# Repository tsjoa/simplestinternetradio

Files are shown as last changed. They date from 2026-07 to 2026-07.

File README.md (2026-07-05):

# Simplest Ever Internet Radio 📻

The simplest, cheapest, and easiest way to connect your classic stereo receiver to the internet and stream high-quality audio! Powered by an **ESP32-S3 Super Mini**, a **PCM5102A (TS1943W) DAC**, and **ESPHome**, this project integrates seamlessly into **Home Assistant** as a standard media player.

With only 6 wires, a mini breadboard, and basic soldering (just header pins and 4 configuration pads), you can build a premium network audio streamer in under 30 minutes.

---

## 🛠️ Hardware Requirements

*   **[ESP32-S3 Development Board](https://www.aliexpress.com/item/1005006637349060.html)** (with PSRAM enabled—see list below)
*   **[PCM5102A (TS1943W) DAC Breakout Board](https://www.aliexpress.com/item/1005010329558215.html)**
*   **Mini Breadboard**
*   **6 Jumper Wires**
*   **USB-C Power Cable & Power Brick**
*   **3.5mm to RCA** (or 3.5mm to 3.5mm) audio cable (to connect the DAC to your stereo's `AUX` or `Line In` port)

### 💡 Verified ESP32-S3 Boards (PSRAM Required)

Since this project buffers audio to prevent stuttering, a board with active PSRAM is mandatory. The following boards have been verified to work:

#### 1. ESP32-S3 Super Mini (PSRAM Edition)
*   **Memory:** 4MB Flash + **2MB PSRAM** (ESP32-S3R2 chip)
*   **PSRAM Type:** Embedded Quad SPI (QSPI)
*   **Pros:** Ultra-compact form factor; fits anywhere.
*   **What to look out for:** Ensure the listing explicitly mentions "PSRAM" or "R2", as there is a cheaper, flash-only version of this exact board that will crash with `ESP_ERR_NO_MEM`.

#### 2. Official Espressif ESP32-S3-DevKitC-1-N8R8 or -N16R8
*   **Memory:** 8MB or 16MB Flash + **8MB PSRAM** (ESP32-S3-WROOM-1 module)
*   **PSRAM Type:** External Octal SPI (OPI)
*   **Pros:** Standard flagship development board, uses the fastest Octal PSRAM, maximum stability in ESPHome.
*   **What to look out for:** Make sure the part number contains the **R8** suffix (e.g., `N8R8`). Avoid the `N8` or `N16` models, which have zero PSRAM.

#### 3. Waveshare ESP32-S3-Zero
*   **Memory:** 4MB Flash + **2MB PSRAM** (ESP32-S3R2 chip)
*   **PSRAM Type:** Embedded Quad SPI (QSPI)
*   **Pros:** Extremely tiny, castellated holes for direct soldering, uses a single USB-C port with an onboard CH343 serial bridge chip for hassle-free flashing.
*   **What to look out for:** Like the Super Mini, double-check that the vendor specifies the PSRAM variant.

#### 4. Seeed Studio XIAO ESP32S3
*   **Memory:** 8MB Flash + **8MB PSRAM**
*   **PSRAM Type:** External Octal SPI (OPI)
*   **Pros:** High-quality, tiny thumbnail form factor, equipped with 8MB of fast Octal PSRAM. Very popular for compact audio and camera projects.
*   **What to look out for:** Do not accidentally buy the standard *XIAO ESP32C3* or *XIAO ESP32S3 Sense* (unless you specifically want the detachable camera addon card that comes with the Sense kit).

#### 🛒 Quick Buying Checklist Rule of Thumb:
When clicking "Add to Cart" on marketplaces like AliExpress or Amazon, look for the variant dropdown menus. **Always select the option labeled `OPI` or `With PSRAM`.** If an option is labeled `qSPI / No PSRAM` or just lists a single number like `16MB`, skip it.

---

## 📐 Wiring Diagrams & Setup

You can find both the Fritzing schematic diagrams and actual reference photographs of the breadboard assembly below. 

The original Fritzing project file is available here: [Simplest Internet Radio HomeAssistant.fzz](Simplest%20Internet%20Radio%20HomeAssistant.fzz)

### 1. Complete Schematic & Build (All Parts)
Here is the Fritzing diagram and the corresponding completed hardware assembly. The boards sit directly over the flat jumper wire routing:

| Fritzing Schematic (All Parts) | Physical Completed Build |
| :---: | :---: |
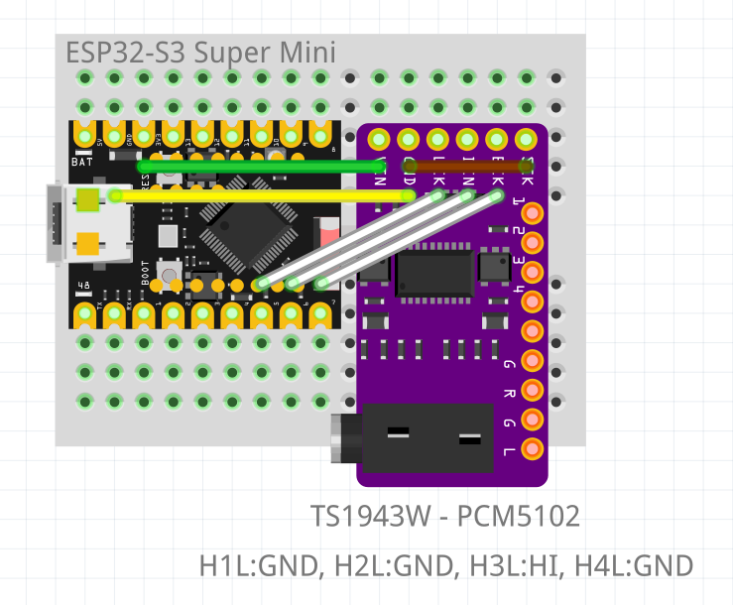
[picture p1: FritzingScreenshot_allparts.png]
All Parts Breadboard Diagram
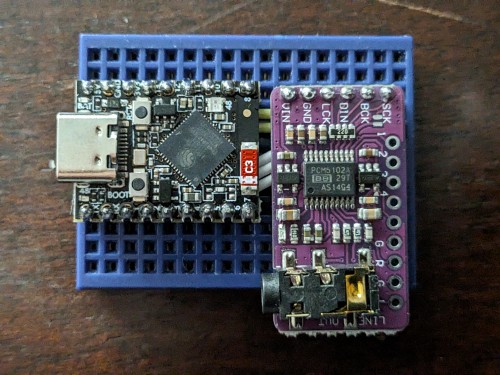
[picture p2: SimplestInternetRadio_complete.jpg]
Physical Completed Build
|  |  |

### 2. Wire Connections Only (Underneath the Boards)
Since the modules cover the jumper wires, here is the diagram and reference photo showing the flat wire routing on the mini breadboard before plugging in the boards:

| Fritzing Wire Connections | Physical Wire Routing |
| :---: | :---: |
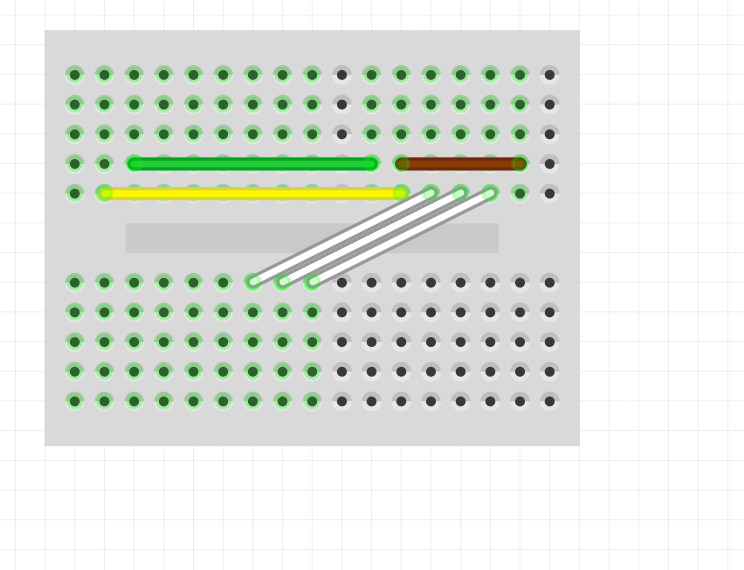
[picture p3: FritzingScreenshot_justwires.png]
Wire Connections Only
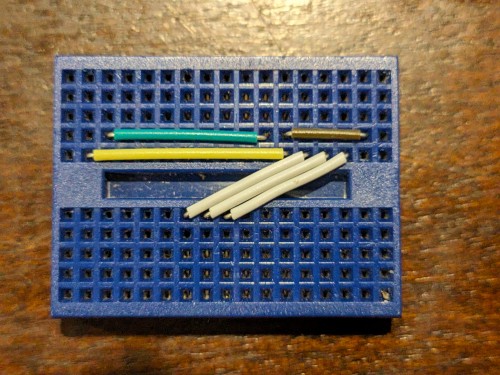
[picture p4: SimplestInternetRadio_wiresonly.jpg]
Physical Wire Routing
|  |  |

---

## 🔌 Step-by-Step Assembly Guide

### Step 1: Hard-Solder the Configuration Bridges

On the back of the PCM5102A breakout board, there are four sets of three-pad jumpers labeled H1L through H4L. Use a soldering iron and a small dab of solder to bridge the **Center** pad to either the **L** (Low) or **H** (High) pad as follows:

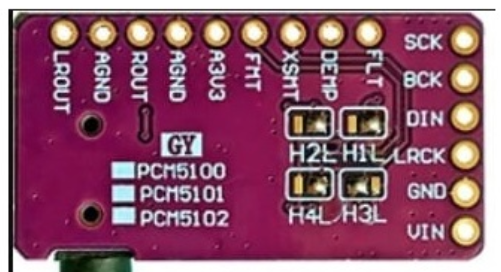
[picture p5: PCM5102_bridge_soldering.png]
PCM5102 Bridge Soldering Diagram


| Jumper | Label | Connection | Setting Details |
| :--- | :--- | :--- | :--- |
| **H1L** | FLT | **Center** ➔ **L** | Normal Latency filter |
| **H2L** | DEMP | **Center** ➔ **L** | De-emphasis Off |
| **H3L** | XSMT | **Center** ➔ **H** | **Unmuted** (Crucial—otherwise no sound!) |
| **H4L** | FMT | **Center** ➔ **L** | I2S Format |

---

### Step 2: Wire the Hardware

Pop your development board and the PCM5102A onto your mini breadboard, and connect them using your jumper wires. 

Here are the pin connections for both the **ESP32-S3 Super Mini** and the **ESP32-C3 Super Mini**:

| PCM5102A DAC Pin | ESP32-S3 Super Mini | ESP32-C3 Super Mini | Function / Description |
| :--- | :--- | :--- | :--- |
| **VCC** (3.3V) | **3V3** | **3V3** (Right side Pin 1) | Main power supply (3.3V) |
| **GND** | **GND** | **GND** (Left side Pin 2 or Right side Pin 2) | System ground |
| **SCK** ➔ **GND** | *N/A* (Ground loop) | *N/A* (Ground loop) | Forces the DAC to generate its own internal clock |
| **LCK** (LRCK) | **GPIO5** | **GPIO10** (Left side Pin 3) | Left/Right Clock (I2S) |
| **DIN** | **GPIO6** | **GPIO20** (Right side Pin 5) | Data In (I2S) |
| **BCK** | **GPIO7** | **GPIO21** (Right side Pin 4) | Bit Clock (I2S) |

> [!IMPORTANT]
> Since the ESP32-C3 Super Mini uses **GPIO 20** and **GPIO 21** for I2S, which are the default hardware serial UART pins, the configuration redirects the `logger` output to the native USB port (`USB_SERIAL_JTAG`). This avoids any digital noise or interference (loud screeching or stuttering) from debug logs.

*Finally, connect the DAC's 3.5mm audio jack to your stereo's `AUX` or `Line In` port using your audio cable.*

---

## 💻 Software Deployment

### 1. Copy the ESPHome Configuration
Select the appropriate configuration file for your micro-controller:
*   **For ESP32-S3 (Recommended):** Use [Simplest Internet Radio HomeAssistant.yaml](Simplest%20Internet%20Radio%20HomeAssistant.yaml).
*   **For ESP32-C3:** Use [Simplest Internet Radio ESP32-C3.yaml](Simplest%20Internet%20Radio%20ESP32-C3.yaml).

Ensure your Wi-Fi details, API keys, and OTA passwords are configured in your ESPHome `secrets.yaml` file.

### 2. Clean Build (Mandatory for ESP32-S3)
Before compiling, you must perform a clean build to apply low-level changes (like PSRAM/SPIRAM enablement for the S3):
1. Open your ESPHome Dashboard.
2. Click the three dots on the device card (`esp32-stereo-link` or `esp32-c3-stereo-link`).
3. Select **Clean Build**.

### 3. Compile and Download
Compile the configuration and download the **factory binary file** to your local computer (e.g., `esp32-stereo-link-firmware.factory.bin` or `esp32-c3-stereo-link-firmware.factory.bin`).

### 4. Flash the Board
Connect your board to your computer via USB and run the command matching your chip:

#### For ESP32-S3:
```bash
sudo esptool --chip esp32s3 --no-stub --port /dev/ttyACM0 write_flash -z 0x0 ~/Downloads/esp32-stereo-link-firmware.factory.bin
```

#### For ESP32-C3:
```bash
sudo esptool --chip esp32c3 --no-stub --port /dev/ttyACM0 write_flash -z 0x0 ~/Downloads/esp32-c3-stereo-link-firmware.factory.bin
```
*(Adjust `/dev/ttyACM0` and the file path according to your OS and download location).*

---

## 🎵 Streaming Audio via Home Assistant

### 1. Discovery
Once the board flashes, boots up, and connects to your Wi-Fi network, Home Assistant will automatically discover it. A new `media_player.stereo_internet_radio` entity will appear under the ESPHome integration.

### 2. Initialize Volume
> [!IMPORTANT]
> If the device connects but stays silent during playback, open the ESP32's local IP address in a web browser. Slide the volume up from **0%** to **80%** to initialize the internal volume state.

### 3. Stream a Station
You can play streams by calling the `media_player.play_media` service. For example, to play Radio Paradise:

```yaml
service: media_player.play_media
target:
  entity_id: media_player.stereo_internet_radio
data:
  media_content_id: "http://stream.radioparadise.com/mp3-192"
  media_content_type: "music"
```

Enjoy your high-fidelity, ultra-simple internet radio! 📻🎶

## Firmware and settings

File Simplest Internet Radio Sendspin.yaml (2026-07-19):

substitutions:
  name: sendspin-stereo-radio
  friendly_name: "Sendspin Stereo Radio"
  startup_sound_file: Home_Connected
  media_sample_rate: 48000

esphome:
  name: ${name}
  friendly_name: ${friendly_name}
  min_version: 2026.6.0
  name_add_mac_suffix: true
  project:
    name: realdeco.sendspin_zero
    version: "2026.6.0"
  on_boot:
    priority: -100
    then:
      - script.execute: led_red

esp32:
  variant: esp32s3
  framework:
    type: esp-idf

logger:
  level: warn

api:
  encryption:
    key: !secret api_encryption_key
  on_client_connected:
    - lambda: |-
        if (!id(boot_sound_played)) {
          id(boot_sound_played) = true;
          if (id(startup_sound_switch).state) {
            id(play_sound)->execute(true, std::string("ready_sound"));
          }
        }

ota:
  - platform: esphome
    id: ota_esphome
    password: !secret ota_password

wifi:
  ssid: !secret wifi_ssid
  password: !secret wifi_password
  output_power: 8.5dB
  ap:
    ssid: ${friendly_name}
    password: !secret ap_password
    ap_timeout: 15s

improv_serial:

captive_portal:

psram:
  mode: quad
  speed: 80MHz
  ignore_not_found: false

# -------------------------------------------------------------------
# DIGITAL AUDIO (I2S) PIPELINE CONFIGURATION
# Matches pinout from Simplest Internet Radio HomeAssistant.yaml:
#   LRCLK (LCK) -> GPIO5
#   BCLK        -> GPIO7
#   DOUT (DIN)  -> GPIO6
# -------------------------------------------------------------------
sendspin:
  id: sendspin_hub

i2s_audio:
  - id: i2s_audio_bus
    i2s_lrclk_pin: GPIO5
    i2s_bclk_pin: GPIO7

speaker:
  - platform: i2s_audio
    id: box_speaker
    i2s_audio_id: i2s_audio_bus
    i2s_dout_pin: GPIO6
    dac_type: external
    channel: stereo

  - platform: mixer
    id: mixing_speaker
    output_speaker: box_speaker
    num_channels: 2
    source_speakers:
      - id: announcement_mixing_input
      - id: media_mixing_input

  - platform: resampler
    id: announcement_resampling_speaker
    output_speaker: announcement_mixing_input
    sample_rate: ${media_sample_rate}
    bits_per_sample: 16

  - platform: resampler
    id: media_resampling_speaker
    output_speaker: media_mixing_input
    sample_rate: ${media_sample_rate}
    bits_per_sample: 16

audio_file:
  - id: ready_sound
    file: https://github.com/RealDeco/xiaozhi-esphome/raw/main/sounds/${startup_sound_file}.flac

media_source:
  - platform: audio_file
    id: audio_file_announcement_source
  - platform: audio_http
    id: http_announcement_source
  - platform: audio_http
    id: http_media_source
  - platform: sendspin
    id: sendspin_media_source

media_player:
  - platform: sendspin
    id: sendspin_group_media_player
    name: Sendspin Group Media Player

  - platform: speaker_source
    id: external_media_player
    name: Media Player

    announcement_pipeline:
      format: FLAC
      num_channels: 1
      sample_rate: ${media_sample_rate}
      speaker: announcement_resampling_speaker
      sources:
        - audio_file_announcement_source
        - http_announcement_source

    media_pipeline:
      format: FLAC
      num_channels: 2
      sample_rate: ${media_sample_rate}
      speaker: media_resampling_speaker
      sources:
        - http_media_source
        - sendspin_media_source
    volume_increment: 0.05
    volume_min: 0.4
    volume_max: 0.9

    on_state:
      then:
        - lambda: |-
            using media_player::MediaPlayerState;
            auto state = id(external_media_player).state;
            if (
              state == MediaPlayerState::MEDIA_PLAYER_STATE_PLAYING ||
              state == MediaPlayerState::MEDIA_PLAYER_STATE_ANNOUNCING
            ) {
              id(led_green).execute();
            } else {
              id(led_red).execute();
            }

script:
  - id: play_sound
    parameters:
      priority: bool
      sound_file: string
    then:
      - if:
          condition:
            lambda: return priority;
          then:
            - media_player.stop:
                id: external_media_player
                announcement: true
      - lambda: |-
          if ((id(external_media_player).state != media_player::MediaPlayerState::MEDIA_PLAYER_STATE_ANNOUNCING) || priority) {
            id(external_media_player)
              ->make_call()
              .set_media_url("audio-file://" + sound_file)
              .set_announcement(true)
              .perform();
          }

  - id: led_red
    then:
      - light.turn_on:
          id: led
          red: 100%
          green: 0%
          blue: 0%
          brightness: 100%

  - id: led_green
    then:
      - light.turn_on:
          id: led
          red: 0%
          green: 100%
          blue: 0%
          brightness: 100%

switch:
  - platform: template
    id: startup_sound_switch
    name: Startup sound
    icon: "mdi:card-text-outline"
    entity_category: config
    optimistic: true
    restore_mode: RESTORE_DEFAULT_ON
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

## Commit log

2026-07-05 Initial commit: Simplest Ever Internet Radio project
    [Simplest Internet Radio HomeAssistant.fzz]
2026-07-05 Update wiring to 3.3V to prevent frying PCM5102, add ESP32-C3 config, and update schematics
    [Simplest Internet Radio HomeAssistant.fzz]
2026-07-05 Update Fritzing PNG diagrams for 3V3 wiring
